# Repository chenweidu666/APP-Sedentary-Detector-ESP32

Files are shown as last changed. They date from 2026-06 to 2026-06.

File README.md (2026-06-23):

# Sedentary Detector ESP32 - 久坐检测器

<p align="center">
  
  
  
  
  
</p>

基于 **ESP32-WROOM-32** + **GY-87**（10DOF，固件用 MPU6050）+ OLED 的椅子久坐检测器。安装在椅子坐垫下方，通过检测坐垫倾斜角度变化判断是否有人坐，超时提醒起身活动。PM11 锂电包供电，USB 充电，**PM11 自带开关**控制电源。

**开发策略**: 全部使用现成开发板模块，设计一块载板 PCB 将各模块插接互连，配合 3D 打印底座固定。模块可拆卸替换，方便快速迭代。

## 当前进度

| 模块 | 状态 |
|---|---|
| 硬件方案 | ✅ 已完成 (ESP32-WROOM-32 + **GY-87** + PM11) |
| 载板 PCB 设计 | 🔧 v0.4 待改版 v0.5（J2 改 GY-87 引脚顺序） |
| Wokwi 仿真 | ✅ 已完成 (ESP32 + MPU6050, 检测算法验证) |
| 固件开发 | 🔧 联调中 (GY-87 / MPU6050 已验证，竖放 ≈90°) |
| 3D 底座 | ⏳ 待设计 |
| 采购 | ⏳ 待下单 |

## 检测原理

MPU6050 加速度计测量重力向量方向。坐下时椅子坐垫受力产生微小倾斜，加速度分量变化，据此判断有人/无人状态。

```
无人状态                         有人状态
┌──────────────┐               ┌──────────────┐
│   ═══坐垫═══  │               │ 👤 ══坐垫══↘  │
│    (水平)     │               │   (倾斜 1-3°) │
│              │               │              │
│  [MPU6050]   │               │  [MPU6050]   │
│  Z轴 = 1g   │               │  Z轴 < 1g    │
│  X/Y轴 ≈ 0  │               │  X/Y轴 ≠ 0   │
└──────────────┘               └──────────────┘
  角度 ≈ 0°                      角度 ≈ 1-3° → 有人！
```

辅助判据：
- **振动检测**: 人坐着会产生持续微振动（翻身、打字、呼吸），无人时完全静止
- **坐下/站起冲击**: 坐下和站起瞬间加速度有明显脉冲

## 系统架构

```
                ┌──────────────────────────────────┐
                │        3D 打印底座 (椅子下方)       │
                │  ┌─ 载板 PCB ─────────────────┐  │
                │  │                            │  │
                │  │  [GY-87]    I2C   [ESP32]  │  │
                │  │  MPU6050 ══════  WROOM-32 │──→ BLE / WiFi
                │  │  (插接)    SDA    (插接)    │  │
                │  │           SCL     ↑ 5V     │  │
                │  │                   │        │  │
                │  │  [PM11]───────────┘        │  │
                │  │  电池包                     │  │
                │  │  (JST)                      │  │
                │  └────────────────────────────┘  │
                │      ↑ PM11 USB 充电口外露        │
                └──────┼───────────────────────────┘
                       │
                    USB 充电
```

## 硬件成本

| 物料 | 型号 | 单价 | 说明 |
|---|---|---|---|
| 主控模块 | ESP32-WROOM-32 开发板 (DevKitC) | ¥35.67 | CP2102 USB 串口, WiFi+BT |
| IMU 模块 | **GY-87**（10DOF，固件用 MPU6050） | ~¥30 | 含 BMP180(`0x77`)，I2C 见 HARDWARE.md |
| 电池模块 | PM11锂电池包 (3.7V+充电+升压5V/2.4A) | ¥19.00 | 内置电池+充电+升压+开关 |
| OLED | SSD1306 128×64 I2C | ~¥8 | 与 GY-87 共 I2C 总线 |
| 载板 PCB | 定制 PCB (嘉立创打样) | ~5.00 | 5片起打, 排母座插接各模块 |
| 排母座 | 2.54mm 排母 | ~2.00 | 焊在载板上, 模块插入 |
| 电池接口 | JST-PH 2.0 座子 | ~0.50 | PM11 电池可插拔 |
| 底座 | 3D 打印 (PLA) | ~3.00 | 固定载板 PCB + 电池 |
| **合计** | | **~¥90** | |

## 文档索引

| 文档 | 内容 |
|---|---|
| [hardware/HARDWARE.md](hardware/HARDWARE.md) | 硬件选型、BOM、接线图、供电设计、PCB载板设计、3D底座 |
| [firmware/FIRMWARE.md](firmware/FIRMWARE.md) | 固件架构、检测算法、状态机、BLE/WiFi通信、功耗管理 |
| [firmware/README.md](firmware/README.md) | 固件编译、烧录、串口联调 |

## 项目结构

```
02-APP-Sedentary-Detector-ESP32/
├── README.md                    # 项目总览 (本文件)
├── hardware/
│   ├── HARDWARE.md              # 硬件设计文档 (选型、BOM、接线、供电、PCB、3D底座)
│   ├── images/                  # 引脚图、模块照片
│   └── kicad/                   # KiCad 载板工程
├── simulation/                  # Wokwi 仿真
│   ├── diagram.json             # 电路连接
│   ├── wokwi.toml               # Wokwi 配置
│   └── src/
│       └── main.cpp             # 仿真固件
├── firmware/                    # ESP32-WROOM-32 固件 (PlatformIO)
│   ├── README.md                # 联调指南
│   ├── FIRMWARE.md              # 架构与算法设计
│   ├── src/
│   │   ├── main.cpp             # 主逻辑 + 串口 bring-up
│   │   ├── detector.h / .cpp    # 久坐检测状态机
│   │   └── config.h             # 引脚与阈值
│   └── platformio.ini           # board=esp32dev
├── mechanical/                  # 3D 打印底座
│   └── base.stl                 # 底座模型 (待设计)
└── docs/
    └── calibration.md           # 校准指南 (待编写)
```

## 开发计划

### Phase 1: 仿真验证 (当前)

- [x] Wokwi 仿真 (ESP32 + MPU6050 + LED)
- [x] 角度检测算法验证
- [x] 久坐计时逻辑
- [ ] 在 Wokwi 中调整参数，确认检测准确率
- [x] 购买 ESP32-WROOM-32 开发板（已联调 USB 烧录）
- [x] GY-87 + ESP32 杜邦线联调（I2C `0x68`/`0x77`）
- [ ] 载板 PCB v0.5：J2 按 GY-87 改走线并打样
- [ ] 面包板搭建原型，验证接线
- [ ] 实测椅子坐下/站起时的角度变化数据
- [ ] 确定安装位置和固定方式

### Phase 2: 载板 PCB + 固件开发

- [ ] 载板 PCB v0.5（J2 GY-87 走线）打样、焊接
- [ ] 固件移植 (Wokwi → 真实硬件)
- [ ] MPU6050 DMP 姿态解算
- [ ] Deep Sleep + RTC 定时唤醒
- [ ] MPU6050 Motion Interrupt 唤醒
- [ ] BLE 广播实现
- [ ] 电池电量检测 (ADC)
- [ ] 功耗实测与优化

### Phase 3: 整合测试

- [ ] 3D 底座设计与打印
- [ ] 载板 + 电池装入底座
- [ ] 安装到椅子上
- [ ] 长时间稳定性测试 (24h+)
- [ ] 误判率统计与阈值调优
- [ ] 实际功耗测量

---

## License

MIT

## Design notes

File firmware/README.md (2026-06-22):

# 固件联调指南

**平台**：ESP32-WROOM-32 + IO 扩展板  
**传感器**：**GY-87**（固件仅使用板载 MPU6050 @ `0x68`）

## 接线（已验证）

| GY-87 丝印 | 扩展板 | GPIO |
| --- | --- | ---- |
| VCC_IN | **3V3** | — |
| GND | **GND** | — |
| SCL | **D5** | GPIO5 |
| SDA | **D4** | GPIO4 |
| INTA | **D2** | GPIO2（可选） |
| 3.3V / FSYNC / DRDY | 不接 | — |

载板 J2 引脚顺序见 [hardware/HARDWARE.md](../hardware/HARDWARE.md)。

## 安装姿态

**竖直立放**（台架）：基准角约 **±90°**（实测 ~97°），看 **delta** 判人。  
**水平安装**（坐垫下）：基准约 0°，装好后串口 `c` 重校准。

## 编译烧录

```bash
cd Projects/02-APP-Sedentary-Detector-ESP32/firmware
pio run -t upload
pio device monitor
```

`MOCK_MPU6050=0`（已接 GY-87）；无传感器时改为 `1`。

## 串口示例

```
[I2C] scan SDA=GPIO4 SCL=GPIO5
  device 0x68
  device 0x77
[MPU6050] connected
[CAL] baseline=97.17 deg (mock=0)
```

`0x77` = GY-87 上 BMP180，可忽略。

## 命令

| 键 | 作用 |
|----|---|
| `r` | I2C 重扫 |
| `c` | 重校准 |
| `m` | 切换 mock（无 MPU 时） |

详细架构见 [FIRMWARE.md](FIRMWARE.md)。

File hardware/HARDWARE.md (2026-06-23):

# 硬件设计文档

> **主控**：ESP32-WROOM-32 开发板（ESP32-DevKitC 风格，2×15 排针载板）。非 ESP32-C3。

## 采购链接

| 模块 | 链接 |
| --- | --- |
| ESP32-WROOM-32 开发板 | https://detail.tmall.com/item.htm?id=805161973303&skuId=5879086331469 |
| 陀螺仪模块 | **GY-87**（10DOF，固件用 MPU6050） | 淘宝/立创搜 GY-87 |
| PM11锂电池包 (3.7V+充电+升压5V/2.4A) | https://item.taobao.com/item.htm?id=1007451636387&skuId=6002389453662 |
| 0.96寸 OLED (I2C) | 128×64 SSD1306, 4Pin (VCC/GND/SCL/SDA) | 淘宝搜 0.96 OLED I2C |

---

## 模块引脚

### ESP32-WROOM-32 开发板 (ESP32-DevKitC 风格)

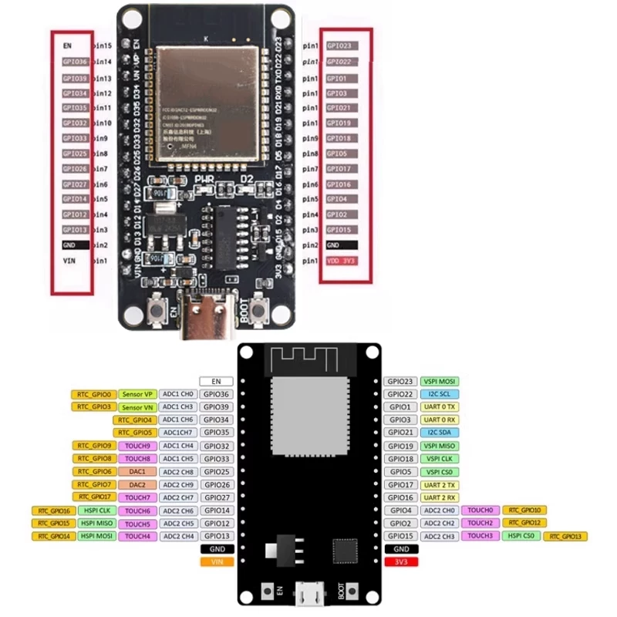
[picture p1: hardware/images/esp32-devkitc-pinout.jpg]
ESP32-WROOM-32 引脚图


```
尺寸: 51.85 × 23.5 mm
引脚: 左列 15pin + 右列 14pin, 2.54mm 间距, 排针间距 23.5mm
安装孔: 4× φ3mm, 距边 3mm
```

#### 左侧引脚 (从上到下, 15 pin)

| Pin | 丝印 | 功能说明 |
| --- | --- | --- |
| 1 | EN | 使能/复位引脚 (高电平有效) |
| 2 | UP (VP) | GPIO36, ADC1_CH0, 仅输入 |
| 3 | UN (VN) | GPIO39, ADC1_CH3, 仅输入 |
| 4 | D34 | GPIO34, ADC1_CH6, 仅输入 |
| 5 | D35 | GPIO35, ADC1_CH7, 仅输入 |
| 6 | D32 | GPIO32, ADC1_CH4 / TOUCH9  |
| 7 | D33 | GPIO33, ADC1_CH5 / TOUCH8  |
| 8 | D25 | GPIO25, ADC2_CH8 / DAC_1 |
| 9 | D26 | GPIO26, ADC2_CH9 / DAC_2 |
| 10  | D27 | GPIO27, ADC2_CH7 / TOUCH7  |
| 11  | D14 | GPIO14, ADC2_CH6 / TOUCH6  |
| 12  | D12 | GPIO12, ADC2_CH5 / TOUCH5  |
| 13  | D13 | GPIO13, ADC2_CH4 / TOUCH4  |
| 14  | GND | 接地 |
| 15  | VIN | 外部电源输入 (5V) |

#### 右侧引脚 (从上到下, 15 pin)

| Pin | 丝印 | 功能说明 |
| --- | ---- | --- |
| 16  | D23  | GPIO23, VSPI MOSI |
| 17  | D22  | GPIO22, I2C SCL (备用) |
| 18  | TXD  | GPIO1, UART0 TXD |
| 19  | RXD  | GPIO3, UART0 RXD |
| 20  | D21  | GPIO21, I2C SDA (备用) |
| 21  | D19  | GPIO19, VSPI MISO |
| 22  | D18  | GPIO18, VSPI SCK |
| 23  | D5 | GPIO5, VSPI SS / I2C SCL |
| 24  | D17  | GPIO17, UART2 TXD |
| 25  | D16  | GPIO16, UART2 RXD |
| 26  | D4 | GPIO4, I2C SDA |
| 27  | D2 | GPIO2, 板载 LED / MPU INT |
| 28  | D15  | GPIO15, U0 RTS |
| 29  | GND  | 接地 |
| 30  | 3V3  | 3.3V 电源输出 |

> ⚠️ 注意事项:
>
> - GPIO34~39 仅输入，无输出、无内上下拉
> - GPIO6~11 被 SPI Flash 占用，不建议使用
> - GPIO12 (D12) 上电影响 Flash 电压 (MTDI)，上电时保持低
> - GPIO0 下载模式 (板子底部 BOOT 按钮)
> - 板载 LED 在 D2 (GPIO2)

### GY-87 模块（正式选型）

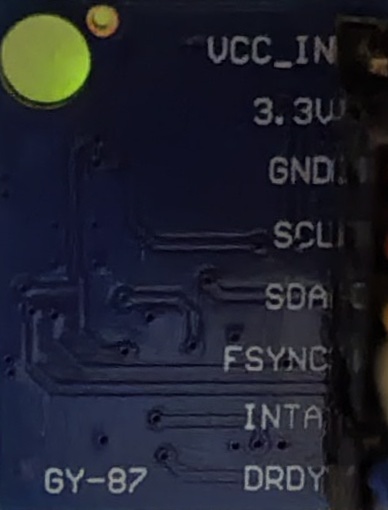
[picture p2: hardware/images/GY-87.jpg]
GY-87 10DOF 模块实物（联调）


10DOF 蓝板，丝印 **GY-87**（MPU6050 + HMC5883L + BMP180）。久坐检测**仅使用 MPU6050 加速度计**，磁力计/气压计与固件无关。

```
引脚: 1 × 8pin 单排, 2.54mm
模块**背面**丝印（如上图，从左至右）: VCC_IN · 3.3V · GND · SCL · SDA · FSYNC · INTA · DRDY
载板 J2 排母（J2 Pin1 = VCC_IN, Pin8 = DRDY），与模块背照丝印顺序一致
```

#### J2 排母引脚映射（载板 / 直插）

| J2 Pin | GY-87 丝印 | 网络 | 连接 |
| --- | --- | ---- | ---- |
| 1 | **VCC_IN** | 3V3 | ESP32 Pin30 (3V3) |
| 2 | **3.3V** | — | **不接**（NC） |
| 3 | **GND** | GND | ESP32 GND |
| 4 | **SCL** | I2C_SCL | ESP32 Pin23 (D5) |
| 5 | **SDA** | I2C_SDA | ESP32 Pin26 (D4) |
| 6 | **FSYNC** | — | NC |
| 7 | **INTA** | MPU_INT | ESP32 Pin27 (D2) |
| 8 | **DRDY** | — | NC |

I2C 扫描：

```
0x68  MPU6050（固件使用）
0x77  BMP180（GY-87 自带，忽略）
0x1E  HMC5883L（可选，固件未用）
```

> **PCB 版本**：原理图 **v0.6** 仅保留 MCU / IMU / OLED / 电源；**PCB v0.4** 走线仍待改后打样。

#### 杜邦线联调（ESP32 扩展板）

| GY-87 丝印 | 扩展板 | 线色（参考） |
| --- | --- | --- |
| VCC_IN | **3V3** | 红 |
| GND | **GND** | 橙 |
| SCL | **D5** | 黄 |
| SDA | **D4** | 绿 |
| INTA | **D2** | 蓝（可选） |
| 3.3V / FSYNC / DRDY | 不接 | — |

联调已验证（2026-06-22）：`0x68` + `0x77`，竖放基准角约 97°，`mock=0` 正常。

---

### 传感器安装姿态

**当前台架**：GY-87 **竖直立放**（芯片面垂直于桌面），非最终椅子安装姿态。

| 姿态 | 典型读数 | 说明 |
| ---- | --- | ---- |
| 水平放置（Z 轴朝上） | 基准角 ≈ **0°** | 最终坐垫下安装目标姿态 |
| **竖直立放（当前）** | 基准角 ≈ **±90°**（实测约 **97°**） | 正常；算法看 **delta**，不是绝对角 |

竖放时上电校准后 `baseline` 约在 **90° 附近**，静止时 `delta` 应 **< 0.5°**、`state=VAC`。  
有人/受压时 **倾斜 1° 以上**（`delta > 1.0°`）才判为 `OCCUPIED`。

**最终产品**：模块应 **水平** 固定在坐垫下方，装好后串口发 `c` 重校准（基准角约 0°）。

### OLED 显示屏

1.54 寸 OLED（SSD1306, 128×64），I2C 接口，与 GY-87 共享 I2C 总线。

| OLED Pin | 网络 | 接 ESP32 |
|---|---|---|
| VCC | 3V3 | Pin30 (3V3) |
| GND | GND | Pin14/29 (GND) |
| SCL | I2C_SCL | Pin23 (D5) |
| SDA | I2C_SDA | Pin26 (D4) |

I2C 地址：**0x3C**（与 GY-87 的 0x68 不冲突）。

### 供电模块 (PM11 电源板)

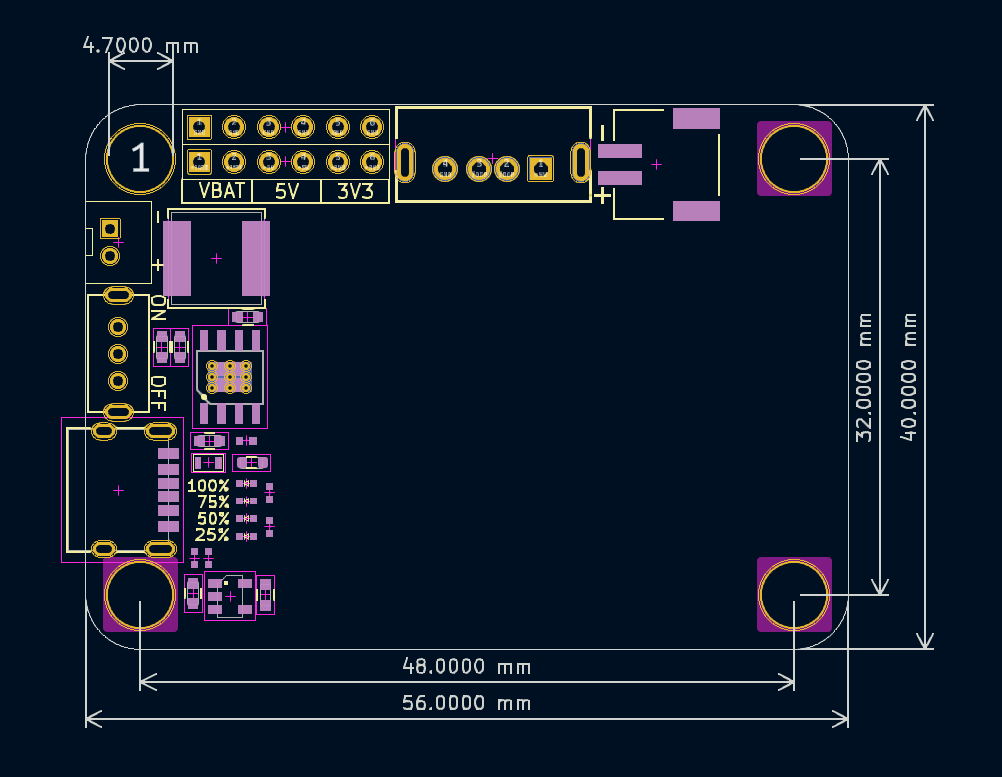
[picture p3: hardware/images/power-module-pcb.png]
供电模块 PCB 布局


集成 **USB 充电 + 锂电管理 + 多路电源输出** 的独立电源板，通过排针向 ESP32 载板供电。

#### 外形尺寸

| 参数 | 值 |
|---|-----|
| PCB 尺寸 | **56.0 × 40.0 mm** |
| 安装孔间距 | 水平 **48.0 mm** × 垂直 **32.0 mm** |
| 安装孔 | 四角 M3（图中标注孔径约 φ4.7 mm，以实物为准） |
| 板厚 | 1.6 mm（常规） |

#### 板载功能

| 功能 | 说明 |
|---|---|
| USB 输入 | 左侧 USB 口，用于充电与外部供电 |
| ON/OFF 开关 | 左侧滑动开关，物理通断输出 |
| 电量指示 | 左侧四档 LED：**100% / 75% / 50% / 25%** |
| 充电管理 | TP4056 类充电 IC + 外围 RC |
| 电池接口 | 顶部 **4Pin** 电池座，丝印 **+ / −** 极性 |
| 电源输出 | 顶部 **2×6** 排针（2.54 mm） |

#### 2×6 排针（本设计关注）

排针位于板子顶部左侧区域；**底排**为常用电源轨（丝印可见）：

| 排针信号 | 说明 | 载板连接 |
|---|---|---|
| **VBAT** | 电池电压（未稳压） | 一般不接 ESP32 |
| **5V** | 升压/稳压 5V 输出 | → ESP32 **Pin15 (VIN)** |
| **3V3** | 3.3V 输出 | 备用；GY-87 从 ESP32 Pin30 取 3V3 |
| GND | 共地 | → ESP32 **Pin14/29** + 载板 GND 铺铜 |

> 上排 6Pin 功能以实物丝印为准；收到模块后**用万用表核对**再焊线。

#### 本设计电源路径

```
USB ──→ [供电模块] ── ON/OFF ──→ 5V 排针 ──→ 载板 ──→ ESP32 Pin15 (VIN)
              │                              │
              └── 电池 (4Pin +/-)             └── GND ──→ ESP32 GND
              └── 电量 LED (100/75/50/25%)

ESP32 板载 LDO: VIN(5V) → 3V3 Pin30 → GY-87 VCC_IN
```

#### 注意事项

1. 电池 **+/−** 切勿接反
2. 开关 OFF 时 ESP32 完全断电；ON 后 5V 才输出到排针
3. 充电时 USB 插入即可，与 ESP32 是否上电无关
4. D2 (GPIO2) 接 GY-87 **INTA**，与 ESP32 板载 LED 共用

---

## 载板全网络表

| 网络 | J1 (ESP32) | J2 (GY-87) | J3 (电源) | J4 (OLED) |
|---|---|---|---|---|
| 3V3 | Pin30 | Pin1(VCC_IN) | — | Pin1(VCC) |
| 5V | Pin15(VIN) | — | Pin2 | — |
| GND | Pin14,29 | Pin3 | Pin1 | Pin2 |
| I2C_SCL | Pin23(D5) | Pin4(SCL) | — | Pin3 |
| I2C_SDA | Pin26(D4) | Pin5(SDA) | — | Pin4 |
| MPU_INT | Pin27(D2) | Pin7(INTA) | — | — |

载板**无**载板级滑动开关与按键；电源通断由 **PM11 自带 ON/OFF** 控制。

---

## 电源路径

```
供电模块 5V 排针 → 载板走线 → ESP32 Pin15 (VIN)
供电模块 GND     → 载板 GND  → ESP32 Pin14/29
```

## 载板 BOM

| # | 元件 | 规格 | 封装 | 数量 |
| - | ---- | ---- | ---- | :--: |
| 1 | ESP32 排母 (左) | 1×15P 2.54mm | 直插 | 1 |
| 2 | ESP32 排母 (右) | 1×15P 2.54mm | 直插 | 1 |
| 3 | GY-87 排母 J2 | 1×8P 2.54mm | 直插 | 1 |
| 4 | OLED 排母 J4 | 1×4P 2.54mm | 直插 | 1 |
| 5 | JST 电源座 J3 | JST-PH 2.0mm 2P | 直插 | 1 |
| 6 | PCB | 100×80mm 2层 1.6mm | - | 5 |

## 固件交互（无载板按键）

校准、切页等通过 **串口命令** 或自动逻辑完成（见 `firmware/FIRMWARE.md`）。

**状态机：** `上电→CALIBRATING(3s)→MONITORING→VACANT/OCCUPIED→ALERT`

**告警解除：** 起身 (Δ<1° 持续3s) 自动解除 → VACANT。

**I2C 设备：**
| 设备 | 地址 |
|---|---|
| MPU6050 (GY-87) | 0x68 |
| BMP180 (GY-87, 忽略) | 0x77 |
| SSD1306 OLED | 0x3C |

## PCB 规格

| 参数 | 值 |
| --- | --- |
| 尺寸 | 100mm × 80mm, 2层 |
| 板厚 | 1.6mm |
| 铜厚 | 1oz |
| 安装孔 | 4× M3 (φ3.2mm), 距边 3mm |
| 线宽 (信号) | 0.254mm |
| 线宽 (电源) | 0.5mm |
| GND | B.Cu 铺铜 |

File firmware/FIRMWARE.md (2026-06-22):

# 固件设计文档

> **平台**：ESP32-WROOM-32（`platformio.ini` 中 `board = esp32dev`）。载板 I2C 为 GPIO4/5，板载 LED 为 GPIO2。
>
> **安装姿态**：台架竖直立放时基准角约 ±90°（实测 ~97°）；水平安装时约 0°。检测使用 `delta = |angle - baseline|`，与绝对角度无关。见 `hardware/HARDWARE.md`。

## 固件架构

```
┌─────────────────────────────────────────────────┐
│                   main.cpp                       │
│              初始化 + 主循环 + Deep Sleep         │
├──────────┬──────────┬───────────┬───────────────┤
│ mpu6050  │ detector │ ble_adv   │    power      │
│ .h/.cpp  │ .h/.cpp  │ .h/.cpp   │   .h/.cpp     │
├──────────┼──────────┼───────────┼───────────────┤
│ MPU6050  │ 久坐检测  │ BLE 广播  │ Deep Sleep    │
│ I2C 驱动  │ 状态机    │ 管理      │ 电源管理      │
│ DMP 姿态  │ 角度判定  │ 状态上报  │ 电池电量      │
│ 加速度读取 │ 滞回去抖  │ 心跳包    │ ADC 检测      │
└──────────┴──────────┴───────────┴───────────────┘
                    │
              config.h
           参数配置 (阈值/时间)
```

## 检测算法

### 状态机

```
            坐下 (角度变化 > 阈值, 持续 3s 确认)
  ┌────────┐ ─────────────────────→ ┌─────────┐
  │  无人   │                        │  有人    │
  │(VACANT)│ ←───────────────────── │(OCCUPIED)│
  └────────┘  站起 (角度恢复, 持续 5s) └────┬────┘
                                        │
                                  连续坐 ≥ 45min
                                        ↓
                                  久坐提醒 (BLE 通知)
                                        │
                                  每隔 15min 再次提醒
```

### 判定算法

```
1. 基准校准 (上电时):
   - 记录无人状态下的基准倾斜角 baseline_angle

2. 每次唤醒:
   - 读取 MPU6050 加速度数据
   - 计算当前倾斜角 current_angle
   - delta = |current_angle - baseline_angle|
   - 计算振动幅度 vibration (加速度标准差)

3. 判定:
   - delta > 1.0° AND vibration > threshold → 有人
   - delta < 0.5° AND vibration < quiet_threshold → 无人
   - 中间值 → 维持当前状态 (滞回)

4. 去抖:
   - 状态切换需连续 N 次 (3-5次) 确认
```

### 参数配置

| 参数 | 默认值 | 说明 |
|---|---|---|
| 采样间隔 | 2s | Deep Sleep RTC 唤醒周期 |
| 角度阈值 (坐下) | 1.0° | 倾斜角变化超过此值判定有人 |
| 角度阈值 (站起) | 0.5° | 回到此范围内判定无人 (滞回) |
| 去抖次数 | 3 次 | 连续确认次数 |
| 久坐阈值 | 45 min | 连续有人超过此时间触发提醒 |
| 重复提醒间隔 | 15 min | 久坐后每隔此时间再次提醒 |
| 心跳间隔 | 5 min | 定时上报状态 |

---

## 通信方式

### BLE 广播 (默认)

无需配对，通过 BLE Manufacturer Specific Data 广播状态：

```
Manufacturer Specific Data (AD Type 0xFF):

Byte 0-1: Company ID = 0xFFFF (测试用)
Byte 2:   Message Type
            0x01 = 状态变化
            0x02 = 心跳
            0x03 = 久坐提醒
            0x04 = 低电量
Byte 3:   Occupancy State (0x00=无人, 0x01=有人)
Byte 4-5: 久坐时长 (uint16, 分钟)
Byte 6:   电池电量 (0-100%)
Byte 7:   当前倾斜角 (int8, 度×10)
```

### WiFi/MQTT (可选)

通过 WiFi 连接 MQTT Broker，上报到 Home Assistant：

```
Topic: home/chair/desk/status      → "occupied" / "vacant"
Topic: home/chair/desk/duration    → 久坐时长 (分钟)
Topic: home/chair/desk/battery     → 电量 (%)
Topic: home/chair/desk/angle       → 当前倾斜角 (度)
```

> WiFi 模式功耗较高 (~100mA 连接时)，建议仅在状态变化时短暂开启 WiFi 上报后关闭。

---

## 电源管理

### Deep Sleep 策略

```
┌──────────────────────────────────────────────┐
│              Deep Sleep 循环                   │
│                                              │
│  RTC 唤醒 (每 2s)                             │
│     │                                        │
│     ↓                                        │
│  读取 MPU6050 (15ms)                          │
│     │                                        │
│     ↓                                        │
│  检测算法判定                                  │
│     │                                        │
│     ├── 状态变化 → BLE 广播 → Deep Sleep      │
│     ├── 久坐提醒 → BLE 广播 → Deep Sleep      │
│     └── 无变化 → 直接 Deep Sleep              │
│                                              │
│  唤醒源:                                       │
│  1. RTC 定时器 (2s)                           │
│  2. MPU6050 INT (运动中断)                     │
└──────────────────────────────────────────────┘
```

### 唤醒源配置

| 唤醒源 | 配置 | 说明 |
|---|---|---|
| RTC 定时器 | 2000ms | 定期采样 MPU6050 |
| MPU6050 INT | GPIO2, 下降沿 | 运动检测中断，加速响应 |

### 电池电量检测

```
ESP32-WROOM-32 ADC → PM11 电池电压分压

- PM11 输出 5V (升压后), 无法直接测电池电压
- 方案: 在 PM11 电池正负极间加分压电阻
- 选用 ADC1 通道引脚（如 GPIO36/39 等仅输入 ADC 脚），读取分压值换算电量
- 低电量阈值: 3.3V (约 10%)
```

### 功耗优化

| 措施 | 效果 |
|---|---|
| Deep Sleep 2s 周期 | 平均功耗 ~0.15mA |
| MPU6050 读取后进入 standby | 减少传感器功耗 |
| BLE 仅在状态变化时广播 | 减少射频功耗 |
| WiFi 按需开启 | 避免持续连接功耗 |
| 关闭未使用外设 | 减少静态漏电 |

---

## 固件模块设计

### mpu6050.h / .cpp - MPU6050 驱动

```cpp
class MPU6050Driver {
public:
    void init();                    // I2C 初始化
    void calibrate();               // 上电校准基准角度
    float readAngle();              // 读取当前倾斜角
    float readVibration();          // 读取振动幅度 (加速度标准差)
    void setMotionInterrupt();      // 配置运动检测中断
    void sleep();                   // MPU6050 进入低功耗
    void wake();                    // MPU6050 唤醒
};
```

### detector.h / .cpp - 久坐检测算法

```cpp
class SedentaryDetector {
public:
    enum State { VACANT, OCCUPIED };

    void init();                    // 初始化, 记录基准角度
    State update(float angle, float vibration);  // 状态更新
    State getState();               // 获取当前状态
    uint16_t getDuration();         // 获取连续久坐时长 (分钟)
    void reset();                   // 重置计时器
};
```

### ble_adv.h / .cpp - BLE 广播管理

```cpp
class BLEAdvertiser {
public:
    void init();                    // BLE 初始化
    void broadcastState(State state, uint16_t duration,
                        uint8_t battery, int8_t angle);  // 广播状态
    void broadcastHeartbeat();      // 心跳包
    void broadcastAlert();          // 久坐提醒
    void broadcastLowBattery();     // 低电量告警
};
```

### power.h / .cpp - 电源管理

```cpp
class PowerManager {
public:
    void init();                    // 电源初始化
    void enterDeepSleep(uint64_t us);  // 进入 Deep Sleep
    uint8_t readBatteryLevel();     // 读取电池电量 (%)
    bool isLowBattery();            // 低电量判断
};
```

### config.h - 参数配置

```cpp
// 采样参数
#define SAMPLE_INTERVAL_US      2000000ULL    // 2s (us)
#define ANGLE_THRESHOLD_SEAT    1.0f          // 坐下角度阈值 (°)
#define ANGLE_THRESHOLD_STAND   0.5f          // 站起角度阈值 (°)
#define DEBOUNCE_COUNT          3             // 去抖次数

// 久坐参数
#define SEATED_THRESHOLD_MIN    45            // 久坐阈值 (分钟)
#define REMINDER_INTERVAL_MIN   15            // 重复提醒间隔 (分钟)
#define HEARTBEAT_INTERVAL_MIN  5             // 心跳间隔 (分钟)

// 电池参数
#define LOW_BATTERY_THRESHOLD   10            // 低电量阈值 (%)
#define BATTERY_ADC_PIN         GPIO_NUM_36   // ADC1_CH0（仅输入，需外部分压）
```

---

## main.cpp 主流程

```cpp
void setup() {
    // 1. 初始化各模块
    power.init();
    mpu6050.init();
    detector.init();
    ble.init();

    // 2. 校准基准角度 (上电时)
    mpu6050.calibrate();

    // 3. 配置 Deep Sleep 唤醒源
    esp_sleep_enable_timer_wakeup(SAMPLE_INTERVAL_US);
    esp_sleep_enable_ext0_wakeup(MPU6050_INT_PIN, LOW);
}

void loop() {
    // 1. 读取传感器
    float angle = mpu6050.readAngle();
    float vibration = mpu6050.readVibration();

    // 2. 更新检测状态
    SedentaryDetector::State newState = detector.update(angle, vibration);

    // 3. 状态变化时广播
    if (newState != lastState) {
        ble.broadcastState(newState, detector.getDuration(),
                          power.readBatteryLevel(), (int8_t)(angle * 10));
        lastState = newState;
    }

    // 4. 久坐提醒
    if (newState == SedentaryDetector::OCCUPIED &&
        detector.getDuration() >= SEATED_THRESHOLD_MIN) {
        ble.broadcastAlert();
    }

    // 5. 心跳包
    if (millis() - lastHeartbeat > HEARTBEAT_INTERVAL_MIN * 60000) {
        ble.broadcastHeartbeat();
        lastHeartbeat = millis();
    }

    // 6. 进入 Deep Sleep
    mpu6050.sleep();
    esp_deep_sleep_start();
}
```

---

## PlatformIO 工程配置

当前工程（见 `platformio.ini`）：

```ini
[env:esp32dev]
platform = espressif32
board = esp32dev
framework = arduino
monitor_speed = 115200
build_flags =
    -DCORE_DEBUG_LEVEL=3
    -DMOCK_MPU6050=1    ; 无传感器联调时保持 1；接上 MPU6050 后改为 0
lib_deps =
    electroniccats/MPU6050@^1.4.3
```

烧录与串口联调步骤见 [README.md](README.md)。

## 开发工具链

| 工具 | 用途 |
|---|---|
| PlatformIO (VSCode) | 固件开发 IDE |
| Wokwi | 在线仿真验证 |
| ESP-IDF | 底层 SDK (可选) |
| nRF Connect | BLE 广播测试 |
| MQTT Explorer | WiFi/MQTT 调试 |

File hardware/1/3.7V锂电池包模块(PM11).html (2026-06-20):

# emakefun文档中心 (https://docs.emakefun.com/)

emakefun

- 首页 (https://docs.emakefun.com/#/zh-cn/homepage)
- 软件介绍
  - 软件下载 (https://docs.emakefun.com/#/zh-cn/software/software_download.zh-CN)
  - ArduinoIDE2.0介绍 (https://docs.emakefun.com/#/zh-cn/software/arduino_ide/arduino_ide.zh-CN)
  - Mixly2.0使用介绍 (https://docs.emakefun.com/#/zh-cn/software/mixly/mixly)
  - Mind+使用介绍 (https://docs.emakefun.com/#/zh-cn/software/mind_plus/mindplus.zh-CN)
  - Thonny使用介绍 (https://docs.emakefun.com/#/zh-cn/software/thonny/thonny.zh-CN)
  - MagicBlock使用介绍 (https://docs.emakefun.com/#/zh-cn/software/MagicBlock_pic_zh/magicblock)
  - 手机编程软件介绍 (https://docs.emakefun.com/#/zh-cn/software/Mobile_programming/Mobile_programming)
- 驱动安装
  - arduino官方驱动安装 (https://docs.emakefun.com/#/zh-cn/driver/arduino_official_driver/arduino_official_driver)
  - ch340驱动安装方法 (https://docs.emakefun.com/#/zh-cn/driver/ch340_driver/ch340_driver)
  - microbit daplink驱动安装 (https://docs.emakefun.com/#/zh-cn/driver/microbit_daplink_driver/microbit_daplink_driver)
  - esp32 usb驱动安装 (https://docs.emakefun.com/#/zh-cn/driver/esp32_driver/esp32_driver)
- PH2.0模块
  - 基础输入模块
    - 按键模块 (https://docs.emakefun.com/#/zh-cn/ph2.0_sensors/base_input_module/button_module/button_module)
    - ADC按键模块 (https://docs.emakefun.com/)
    - 触摸模块 (https://docs.emakefun.com/#/zh-cn/ph2.0_sensors/base_input_module/touch_module/touch_module_zh-cn)
    - 碰撞开关 (https://docs.emakefun.com/)
    - 旋转电位器 (https://docs.emakefun.com/)
    - 滑动变阻器 (https://docs.emakefun.com/)
    - 旋转编码器 (https://docs.emakefun.com/)
    - 摇杆模块 (https://docs.emakefun.com/#/zh-cn/ph2.0_sensors/base_input_module/rocker_module/rocker_module_zh-cn)
    - 触摸矩阵键盘V3.0 (https://docs.emakefun.com/)
    - 触摸钢琴V2.0 (https://docs.emakefun.com/#/zh-cn/ph2.0_sensors/base_input_module/touch_piano/touch_piano)
    - mini-joystick手柄 (https://docs.emakefun.com/#/zh-cn/ph2.0_sensors/base_input_module/mini-joystick/mini-joystick_zh-cn)
    - 自发电无线开关 (https://docs.emakefun.com/#/zh-cn/gallery)
  - 传感器
    - 声音传感器 (https://docs.emakefun.com/#/zh-cn/ph2.0_sensors/sensors/sound_sensor/sound_sensor)
    - DHT11温湿度 (https://docs.emakefun.com/#/zh-cn/ph2.0_sensors/sensors/dht11/dht11_zh-cn)
    - DHT22温湿度 (https://docs.emakefun.com/#/zh-cn/ph2.0_sensors/sensors/dht22/dht22_zh-cn)
    - AHT20温湿度 (https://docs.emakefun.com/#/zh-cn/ph2.0_sensors/sensors/aht20/aht20_zh-cn)
    - 光敏传感器 (https://docs.emakefun.com/)
    - NTC热敏传感器 (https://docs.emakefun.com/#/zh-cn/ph2.0_sensors/sensors/thermal_sensor/thermal_sensor)
    - LM35温度传感器 (https://docs.emakefun.com/#/zh-cn/ph2.0_sensors/sensors/lm35/lm35)
    - NL50温度传感器 (https://docs.emakefun.com/#/zh-cn/ph2.0_sensors/sensors/temperature_sensor_nl50/nl50_zh-cn)
    - DS18B20温度传感器 (https://docs.emakefun.com/#/zh-cn/ph2.0_sensors/sensors/ds18b20_sensor/ds18b20_sensor)
    - 火焰传感器 (https://docs.emakefun.com/#/zh-cn/ph2.0_sensors/sensors/flame_sensor/flame_sensor_zh-cn)
    - 土壤湿度传感器 (https://docs.emakefun.com/#/zh-cn/ph2.0_sensors/sensors/soil_moisture_sensor/soil_moisture_sensor)
    - 雨滴传感器 (https://docs.emakefun.com/#/zh-cn/ph2.0_sensors/sensors/water_droplets_sensor/water_droplets_sensor)
    - 水深传感器 (https://docs.emakefun.com/#/zh-cn/ph2.0_sensors/sensors/water_depth_sensor/water_depth_sensor)
    - 气体传感器 (https://docs.emakefun.com/#/zh-cn/ph2.0_sensors/sensors/mq_gas_sensor/mq_gas_sensor)
    - 人体热释电传感器 (https://docs.emakefun.com/#/zh-cn/ph2.0_sensors/sensors/human_body_sensor/human_body_sensor)
    - 磁簧开关 (https://docs.emakefun.com/)
    - 霍尔开关 (https://docs.emakefun.com/#/zh-cn/ph2.0_sensors/sensors/hall_switch/hall_switch)
    - 灰度传感器 (https://docs.emakefun.com/#/zh-cn/ph2.0_sensors/sensors/grayscale_sensor/grayscale_sensor)
    - 震动传感器 (https://docs.emakefun.com/#/zh-cn/ph2.0_sensors/sensors/shock_sensor/shock_sensor)
    - 四向倾斜开关 (https://docs.emakefun.com/#/zh-cn/ph2.0_sensors/sensors/tilt_switch_sensor/tilt_switch_sensor_zh-cn)
    - 压力传感器 (https://docs.emakefun.com/#/zh-cn/ph2.0_sensors/sensors/pressure_sensor/pressure_sensor)
    - RGB超声波传感器 (https://docs.emakefun.com/#/zh-cn/ph2.0_sensors/sensors/rus_04/rus_04)
    - 普通超声波传感器 (https://docs.emakefun.com/#/zh-cn/ph2.0_sensors/sensors/us04_us03/us04_us03)
    - 红外接收模块 (https://docs.emakefun.com/#/zh-cn/ph2.0_sensors/sensors/infrared_receiver/infrared_receiver_zh-cn.md)
    - 红外避障 (https://docs.emakefun.com/)
    - 红外寻光避障 (https://docs.emakefun.com/#/zh-cn/gallery)
    - 红外计数传感器 (https://docs.emakefun.com/#/zh-cn/ph2.0_sensors/sensors/Infrared_counter/Infrared_counter)
    - 红外循迹模块 (https://docs.emakefun.com/#/zh-cn/ph2.0_sensors/sensors/tracking_sensor/tracking_sensor)
    - 五路红外循迹V3.0 (https://docs.emakefun.com/#/zh-cn/ph2.0_sensors/sensors/five_line_tracker_v3/five_line_tracker_v3)
    - 单路灰度循迹模块 (https://docs.emakefun.com/)
    - 五路灰度循迹模块 (https://docs.emakefun.com/)
    - HX711称重模块 (https://docs.emakefun.com/#/zh-cn/)
    - LTR553 (https://docs.emakefun.com/#/zh-cn/)
    - VL53L1X FOV激光测距 (https://docs.emakefun.com/#/zh-cn/ph2.0_sensors/sensors/laser_ranging_sensor/laser_ranging_sensor)
    - PM2.5粉尘传感器 (https://docs.emakefun.com/#/zh-cn/ph2.0_sensors/sensors/pm2.5_dust_sensor/pm2.5_dust_sensor)
  - 执行器
    - 有源蜂鸣器模块 (https://docs.emakefun.com/#/zh-cn/ph2.0_sensors/actuators/active_buzzer/active_buzzer_zh-cn)
    - 无源蜂鸣器模块 (https://docs.emakefun.com/#/zh-cn/ph2.0_sensors/actuators/passive_buzzer/passive_buzzer_zh-cn)
    - SA8302步进电机模块 (https://docs.emakefun.com/#/zh-cn/ph2.0_sensors/actuators/SA8302/SA8302)
    - 空心杯610电机风扇 (https://docs.emakefun.com/)
    - R300C电机风扇 (https://docs.emakefun.com/#/zh-cn/ph2.0_sensors/actuators/R300C/R300C_zh-cn)
    - 继电器模块 (https://docs.emakefun.com/#/zh-cn/ph2.0_sensors/actuators/relay_module/relay_model_zh-cn)
    - 红外发射模块 (https://docs.emakefun.com/#/zh-cn/ph2.0_sensors/actuators/infrared_emitter/infrared_emitter_zh-cn)
    - 激光发射模块 (https://docs.emakefun.com/#/zh-cn/ph2.0_sensors/actuators/laser_emitter/laser_emitter_zh-cn)
    - 振动马达 (https://docs.emakefun.com/#/zh-cn/ph2.0_sensors/actuators/vibrationMotorModule/vibrationMotorModule)
    - 8002A音频放大器 (https://docs.emakefun.com/#/zh-cn/ph2.0_sensors/actuators/8002a_amp_speaker/8002a_amp_speaker)
    - 舵机扩展 (https://docs.emakefun.com/#/zh-cn/ph2.0_sensors/actuators/servo_adapter_zh-cn)
    - MD01单路电机驱动 (https://docs.emakefun.com/#/zh-cn/ph2.0_sensors/actuators/md01/md01_zh-cn)
    - MD02双路电机驱动 (https://docs.emakefun.com/#/zh-cn/ph2.0_sensors/actuators/md02/md02_zh-cn)
    - DM11两路电机驱动模块 (https://docs.emakefun.com/#/zh-cn/ph2.0_sensors/actuators/dm11/dm11)
    - MD40四路编码驱动模块 (https://docs.emakefun.com/#/zh-cn/ph2.0_sensors/actuators/md40/md40)
    - 小型雾化器 (https://docs.emakefun.com/#/zh-cn/ph2.0_sensors/actuators/small_atomizer/small_atomizer_zh-cn)
    - MOS管驱动模块 (https://docs.emakefun.com/#/zh-cn/ph2.0_sensors/actuators/mos_driver_module/mos_driver_module_zh-cn)
  - 显示器
    - LED灯 (https://docs.emakefun.com/#/zh-cn/ph2.0_sensors/displayers/led_module/LED)
    - LCD1602显示屏 (https://docs.emakefun.com/#/zh-cn/ph2.0_sensors/displayers/lcd1602/LCD1602)
    - TM1650四位数码管 (https://docs.emakefun.com/#/zh-cn/ph2.0_sensors/displayers/tm1650/TM1650)
    - TM1637四位时钟数码管 (https://docs.emakefun.com/#/zh-cn/ph2.0_sensors/displayers/tm1637/TM1637)
    - VK16K33四位数码管 (https://docs.emakefun.com/#/zh-cn/ph2.0_sensors/displayers/vk16k33/vk16k33)
    - MAX7289_8x8点阵屏 (https://docs.emakefun.com/#/zh-cn/ph2.0_sensors/displayers/8x8_dot_matrix/8x8LedDisplay)
    - MAX7289_8x32点阵屏 (https://docs.emakefun.com/#/zh-cn/ph2.0_sensors/displayers/8x32_dot_matrix/8x32_dot_matrix)
    - 交通信号灯 (https://docs.emakefun.com/#/zh-cn/ph2.0_sensors/displayers/trafficlight_module/trafficLights)
    - RGB全彩灯 (https://docs.emakefun.com/#/zh-cn/ph2.0_sensors/displayers/rgb_module/RGB)
    - WS2812B RGB灯环 (https://docs.emakefun.com/#/zh-cn/ph2.0_sensors/displayers/ws2812b/ws2812b_zh-cn)
    - 中文字库0.96OLED (https://docs.emakefun.com/#/zh-cn/ph2.0_sensors/displayers/GT20L16S1Y_OLED/GT20L16S1Y_OLED)
    - SWIFT-LCD-13显示屏模块 (https://docs.emakefun.com/#/zh-cn/ph2.0_sensors/displayers/swift_lcd_13/swift_lcd_13)
    - SWIFT-LCD-20显示屏模块 (https://docs.emakefun.com/#/zh-cn/ph2.0_sensors/displayers/swift_lcd_20/swift_lcd_20)
  - 智能模块
    - BMP280大气压传感器 (https://docs.emakefun.com/)
    - TCS34725颜色识别 (https://docs.emakefun.com/#/zh-cn/ph2.0_sensors/smart_module/color_recognition/color_recognition)
    - NLCS11颜色识别 (https://docs.emakefun.com/#/zh-cn/ph2.0_sensors/smart_module/color_sensor_nlcs11/color_sensor_nlcs11)
    - QMC5883L电子指南针罗盘模块 (https://docs.emakefun.com/#/zh-cn/ph2.0_sensors/smart_module/compass/compass)
    - DS1302时钟模块 (https://docs.emakefun.com/#/zh-cn/ph2.0_sensors/smart_module/ds1302/ds1302_rtc)
    - DS1307时钟模块 (https://docs.emakefun.com/#/zh-cn/ph2.0_sensors/smart_module/ds1307/ds1307_rtc)
    - MPU6050六轴陀螺仪 (https://docs.emakefun.com/#/zh-cn/ph2.0_sensors/smart_module/mpu6050/mpu6050)
    - 计步传感器 (https://docs.emakefun.com/#/zh-cn/gallery)
    - GS20手势识别传感器 (https://docs.emakefun.com/#/zh-cn/ph2.0_sensors/smart_module/gesture_recognizer/gesture_recognizer)
    - MP3播放模块 (https://docs.emakefun.com/#/zh-cn/ph2.0_sensors/smart_module/mp3_module/MP3)
    - I2S音频放大器模块 (https://docs.emakefun.com/)
    - ESP8266 MQTT模块 (https://docs.emakefun.com/#/zh-cn/ph2.0_sensors/smart_module/esp8266_mqtt/esp8266_mqtt)
    - ESP32 C2 MQTT模块 (https://docs.emakefun.com/#/zh-cn/ph2.0_sensors/smart_module/esp32_c2_mqtt/esp32_c2_mqtt)
    - LD3320语音识别V2.1 (https://docs.emakefun.com/#/zh-cn/ph2.0_sensors/smart_module/speech_recognizer/speech_recognizer)
    - 离线特定语音识别ASR-V2 (https://docs.emakefun.com/)
    - TTS20 语音合成模块 (https://docs.emakefun.com/#/zh-cn/ph2.0_sensors/smart_module/tts20_module/tts20_module)
    - TTS语音合成V2.1 (https://docs.emakefun.com/#/zh-cn/ph2.0_sensors/smart_module/tts_module/text_to_speech_synthesizer)
    - MIDI数字音乐模块 (https://docs.emakefun.com/#/zh-cn/ph2.0_sensors/smart_module/midi/midi)
    - I2C-IO扩展模块 (https://docs.emakefun.com/)
    - I2C级联扩展器 (https://docs.emakefun.com/)
    - RFID-I2C模块 (https://docs.emakefun.com/#/zh-cn/ph2.0_sensors/smart_module/rfid_mfrc522/rfid_mfrc522)
    - I2S-MEMS麦克风模块 (https://docs.emakefun.com/#/zh-cn/ph2.0_sensors/smart_module/i2s_mems_mic/i2s_mems_mic)
    - PDM麦克风模块 (https://docs.emakefun.com/#/zh-cn/ph2.0_sensors/smart_module/pdm_mic/pdm_mic)
    - 指纹识别模块 (https://docs.emakefun.com/#/zh-cn/)
    - 毫米波雷达模块 (https://docs.emakefun.com/#/zh-cn/)
    - GPS模块 (https://docs.emakefun.com/#/zh-cn/)
    - AI语音助手 (https://docs.emakefun.com/#/zh-cn/ph2.0_sensors/smart_module/ai_voice_assistant/ai_voice_assistant)
- 电源模块
  - 5V5A电源模块(PM01) (https://docs.emakefun.com/#/zh-cn/power_module/PM01/PM01)
  - 升降压5V电源(PM02) (https://docs.emakefun.com/#/zh-cn/power_module/PM02/PM02)
  - MPPT太阳能充电板 (https://docs.emakefun.com/#/zh-cn/power_module/MPPT/MPPT_zh-cn)
  - 3.7V升压充电模块(PM1S-16340) (https://docs.emakefun.com/#/zh-cn/power_module/PM1S-16340/PM1S-16340)
  - 3.7V锂电池包模块(PM11) (https://docs.emakefun.com/#/zh-cn/power_module/PM11/PM11)
    - 概述 (https://docs.emakefun.com/#/zh-cn/power_module/PM11/PM11?id=%e6%a6%82%e8%bf%b0)
    - 模块参数 (https://docs.emakefun.com/#/zh-cn/power_module/PM11/PM11?id=%e6%a8%a1%e5%9d%97%e5%8f%82%e6%95%b0)
      - 功能示意图： (https://docs.emakefun.com/)
    - LED状态说明 (https://docs.emakefun.com/#/zh-cn/power_module/PM11/PM11?id=led%e7%8a%b6%e6%80%81%e8%af%b4%e6%98%8e)
    - 机械尺寸图 (https://docs.emakefun.com/)
  - 7.4V充电电池模块(PM2S-16340) (https://docs.emakefun.com/#/zh-cn/power_module/PM2S-16340/PM2S-16340)
  - 双节18650锂电池充电模块 (https://docs.emakefun.com/#/zh-cn/power_module/18650_2s_li_battery_module/18650_2s_li_battery_module)
  - 三节18650锂电池充电模块 (https://docs.emakefun.com/zh-cn//power_module/18650_3s_li_battery_module.md)
- Arduino产品
  - Nano
    - nano-v3.0 (https://docs.emakefun.com/#/zh-cn/arduino_products/nano/nano/nano)
    - ble-nano (https://docs.emakefun.com/#/zh-cn/arduino_products/nano/ble-nano/README_zh)
    - rf-nano (https://docs.emakefun.com/#/zh-cn/arduino_products/nano/rf-nano/README_zh)
    - nano开发者套件 (https://docs.emakefun.com/#/zh-cn/)
  - Uno系列
    - arduino_uno_r3 (https://docs.emakefun.com/#/zh-cn/arduino_products/uno/arduino_uno_r3/arduino_uno_r3)
    - ble-uno (https://docs.emakefun.com/#/zh-cn/arduino_products/uno/ble-uno/ble_uno)
    - maker-uno (https://docs.emakefun.com/#/zh-cn/arduino_products/uno/maker-uno/maker_uno)
    - PH2.0传感器扩展板 (https://docs.emakefun.com/#/zh-cn/arduino_products/uno/sensorkit/SensorKit)
    - motor_driver_board (https://docs.emakefun.com/#/zh-cn/arduino_products/uno/motor_driver_board/motor_driver_board)
    - hummer-bot (https://docs.emakefun.com/#/zh-cn/arduino_products/uno/hummer-bot/hummer-bot)
    - panther-tank (https://docs.emakefun.com/#/zh-cn/arduino_products/uno/panther_tank/panther_tank)
    - 传感器套件介绍 (https://docs.emakefun.com/#/zh-cn/)
- micro:bit
  - microbit主板介绍 (https://microbit.org/zh-cn/get-started/features/overview/)
  - makecode介绍 (https://docs.emakefun.com/#/zh-cn/microbit/makecode/MakeCode%E4%BD%BF%E7%94%A8%E4%BB%8B%E7%BB%8D)
  - microbit micropython介绍 (https://docs.emakefun.com/#/zh-cn/microbit/microbit_micropython/microbit_micropython)
  - io:bit (https://docs.emakefun.com/#/zh-cn/microbit/IObit/IObit)
  - sensor:bit (https://docs.emakefun.com/#/zh-cn/microbit/sensorbit/sensorbit)
  - motor:bit (https://docs.emakefun.com/#/zh-cn/microbit/motorbit/motorbit)
  - joysitck:bit (https://docs.emakefun.com/#/zh-cn/microbit/joystickbit/joystickbit)
- 乐鑫esp系类
  - esp32软件使用 (https://docs.emakefun.com/#/zh-cn/esp32/esp32_software_instructions/esp32_software_instructions)
  - esp32-devkit-32e (https://docs.emakefun.com/#/zh-cn/esp32/esp32_devkit_32e/esp32_devkit_32e)
  - esp32-uno (https://docs.emakefun.com/#/zh-cn/esp32/esp32-uno/esp32-uno)
  - esp32-iot-board (https://docs.emakefun.com/#/zh-cn/esp32/esp32_iot_board/esp32_iot_board)
  - maker-esp32-mini (https://docs.emakefun.com/#/zh-cn/esp32/maker-esp32-mini/maker-esp32-mini)
  - maker-esp32 (https://docs.emakefun.com/#/zh-cn/esp32/maker_esp32/maker_esp32)
  - maker-esp32-pro (https://docs.emakefun.com/#/zh-cn/esp32/maker_esp32_pro/maker_esp32_pro)
  - esp32-cam V2 (https://docs.emakefun.com/#/zh-cn/esp32/ESP32_CAM/ESP32_CAM)
  - 物联板iot:bit (https://docs.emakefun.com/#/zh-cn/esp32/iotbit/iotbit)
  - nl-esp32-s3-devkitc (https://docs.emakefun.com/#/zh-cn/esp32/nl-esp32-s3-devkitc/README_zh)
  - esp32s3-cam (https://docs.emakefun.com/#/zh-cn/esp32/esp32s3-cam/README_zh)
  - scratch arcade (https://arcade.blockcode.fun/#/zh-cn/intro)
  - AI-VOX3 (https://docs.emakefun.com/#/zh-cn/esp32/ai-vox3/ai-vox3_zh-cn)
  - AI-VOX3扩展板 (https://dcnmu33qx4fc.feishu.cn/docx/Cf49d141voj8JAxNyTJcW5zTned)
  - ESP32-S3-EXPANSION BOARD (https://docs.emakefun.com/#/zh-cn/esp32/esp32-s3-expansion_board/esp32-s3-expansion_board)
- 树莓派
  - 树莓派传感器扩展板 (https://docs.emakefun.com/#/zh-cn/raspberrypi/raspberrypi_sensor_board/raspberrypi_sensor_board)
  - 树莓派电机驱动板 (https://docs.emakefun.com/)
- k210产品
- 开源硬件
  - 机器人驱动板 (https://docs.emakefun.com/#/zh-cn/)
- 外设/配件
  - NL-16 (https://docs.emakefun.com/#/zh-cn/peripheral/nl-16/nl-16_zh-cn)
  - PS2手柄 (https://docs.emakefun.com/#/zh-cn/peripheral/ps2/ps2)
  - PS3蓝牙手柄 (https://docs.emakefun.com/#/zh-cn/peripheral/bluetooth_gamepad_ps3/bluetooth_gamepad_ps3)
  - gamepad (https://docs.emakefun.com/#/zh-cn/peripheral/arduino_gamepad/Programmable_controller)
  - 编码电机 (https://docs.emakefun.com/#/zh-cn/ph2.0_sensors/actuators/hall_encoder_sensor/hall_encoder_sensor)
  - 舵机 (https://docs.emakefun.com/#/zh-cn/peripheral/servo/servo)
  - CodexPad
    - 常见遥控器对比 (https://docs.emakefun.com/#/zh-cn/peripheral/codexpad/wireless_controller_diffrent)
    - CodexPad-C10 (https://docs.emakefun.com/#/zh-cn/peripheral/codexpad/codexpad_c10/codexpad_c10)
    - CodexPad-S10 (https://docs.emakefun.com/#/zh-cn/peripheral/codexpad/codexpad_s10/codexpad_s10)
- 关于我们 (https://docs.emakefun.com/#/zh-cn/about)

# PM11充电升压模块 (https://docs.emakefun.com/)

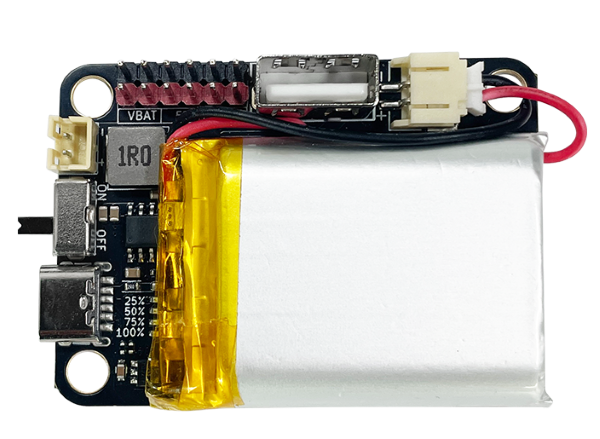
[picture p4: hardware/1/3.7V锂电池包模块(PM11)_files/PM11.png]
PM11


## 概述 (https://docs.emakefun.com/#/zh-cn/power_module/PM11/PM11?id=%e6%a6%82%e8%bf%b0)

该充电模块为3.7V锂电池充电升压5V一体模块，板载1200mA锂电池包。通过TypeC接口即可为板载锂电池提供最高1.2A的安全高效充电。板子上提供了PH2.0-2Pin ，2pin排针锂电池直接输出，USBA口、2pin排针5V/2.4A输出，2Pin排针3.3V 800mA输出。多种电压输出，非常方便应用在多种电压低功耗应用场景需求。且充电芯片自带过充，反接，过载保护。

## 模块参数 (https://docs.emakefun.com/#/zh-cn/power_module/PM11/PM11?id=%e6%a8%a1%e5%9d%97%e5%8f%82%e6%95%b0)

- USB充电 ：TypeC接口 5V最高充电电流1.2A；
- 转换效率：充电升压转换效率90%；
- 电压输出：2pin PH2.0、排针锂电池输出，USBA口 、2pin排针5V/2.4A输，2Pin排针3.3V 800mA输出；
- 电池类型：1200mA锂电池包(充满电压4.2V)；
- 模块尺寸： 56 * 40mm ；
- 安装方式：M4螺钉螺母固定；
- 电池过充/反接/过载保护。

### 功能示意图： (https://docs.emakefun.com/)

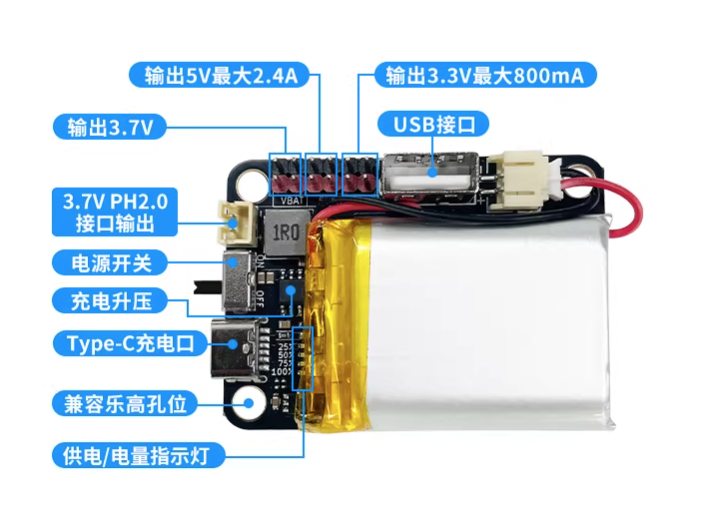
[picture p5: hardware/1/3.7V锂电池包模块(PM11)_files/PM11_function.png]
PM11_function


## LED状态说明 (https://docs.emakefun.com/#/zh-cn/power_module/PM11/PM11?id=led%e7%8a%b6%e6%80%81%e8%af%b4%e6%98%8e)

状态 | 描述
Power指示灯 | 拨动开关ON时，四个LED灯会闪一下，无负载输出的时候，所有灯熄灭
电量 | 4个LED灯分布代表25%，50%，75%，100%电量
充电 | 4灯逐个电流代表在充电中，全亮代表充满

## 机械尺寸图 (https://docs.emakefun.com/)

PM11_assembly

下载PM11平面和3D文件 (https://docs.emakefun.com/zh-cn/power_module/PM11/PM11_3D.zip)

上一篇 (https://docs.emakefun.com/#/zh-cn/power_module/PM1S-16340/PM1S-16340)

3.7V升压充电模块(PM1S-16340)

电源模块

下一篇 (https://docs.emakefun.com/#/zh-cn/power_module/PM2S-16340/PM2S-16340)

7.4V充电电池模块(PM2S-16340)

电源模块

Powered by docsify (https://github.com/docsifyjs/docsify).© 2024emakefun文档中心 (https://github.com/emakefun/emakefun-docsify/).

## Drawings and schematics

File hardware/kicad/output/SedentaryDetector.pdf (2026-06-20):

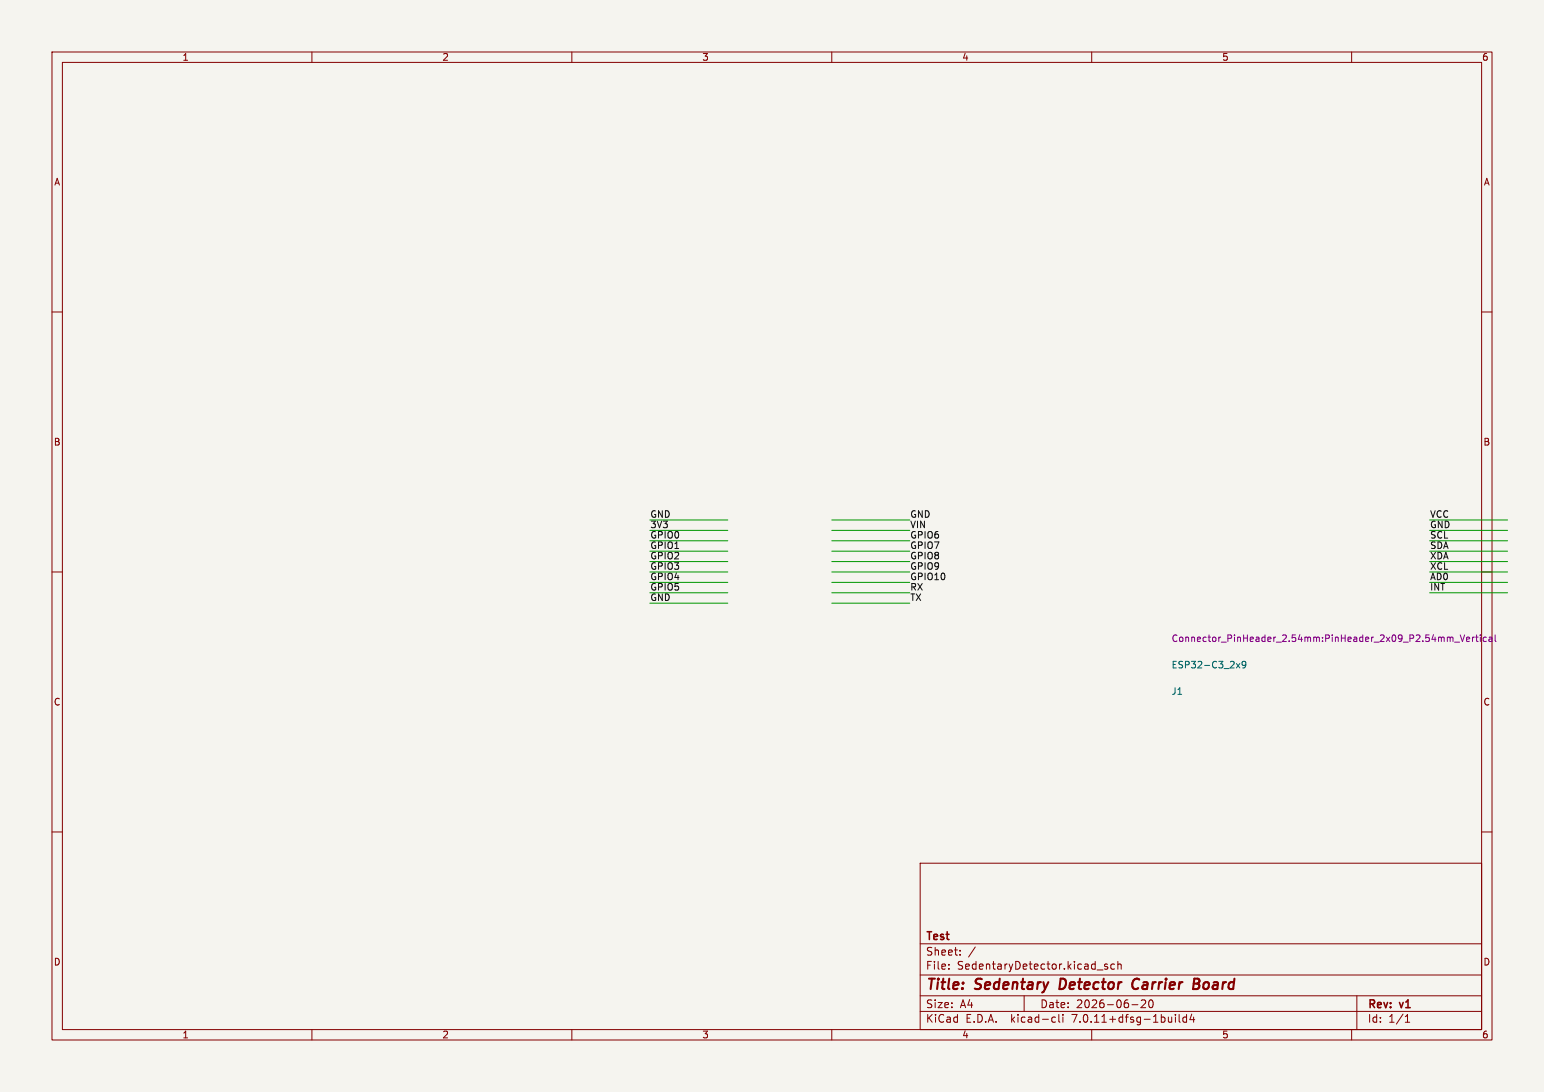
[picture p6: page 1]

File: SedentaryDetector.kicad_sch Sheet: / Test

Id: 1/1 Title: Sedentary Detector Carrier Board

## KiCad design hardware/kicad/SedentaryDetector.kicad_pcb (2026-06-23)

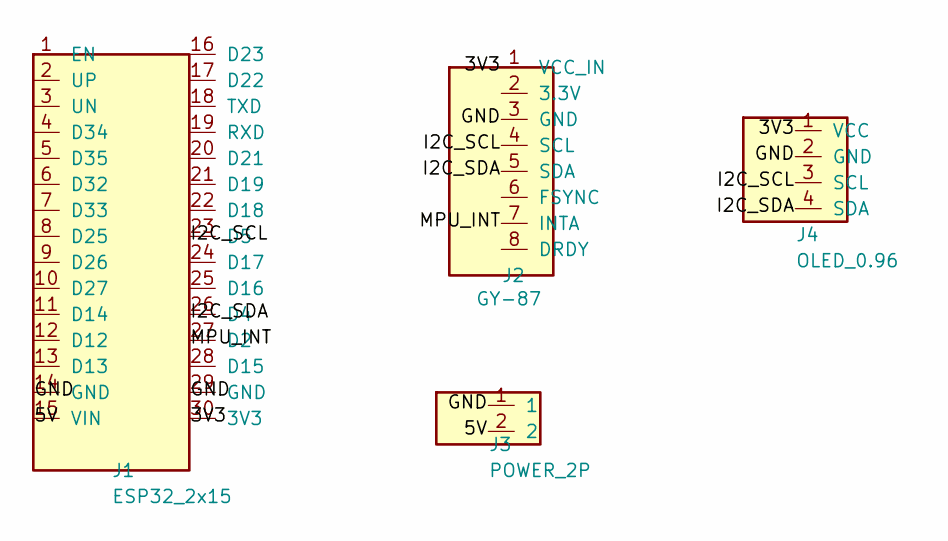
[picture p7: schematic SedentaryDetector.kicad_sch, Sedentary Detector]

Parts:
J1: ESP32_2x15
J2: GY-87
J3: POWER_2P
J4: OLED_0.96

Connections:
3V3: J1.30 (3V3), J2.1 (VCC_IN), J4.1 (VCC)
5V: J1.15 (VIN), J3.2
GND: J1.14 (GND), J1.29 (GND), J2.3 (GND), J3.1, J4.2 (GND)
I2C_SCL: J1.23 (D5), J2.4 (SCL), J4.3 (SCL)
I2C_SDA: J1.26 (D4), J2.5 (SDA), J4.4 (SDA)
MPU_INT: J1.27 (D2), J2.7 (INTA)

Board: 2 copper layers, 8 parts (0 on the bottom side), 6 nets, no tracks yet.

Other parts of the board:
MH1, MH2, MH3, MH4: (no value)

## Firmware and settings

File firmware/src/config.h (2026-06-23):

#pragma once

// GY-87 联调 / 载板 J2：D4=SDA, D5=SCL, D2=INTA（见 hardware/HARDWARE.md）
constexpr int PIN_I2C_SDA = 4;   // D4
constexpr int PIN_I2C_SCL = 5;   // D5
constexpr int PIN_MPU_INT = 2;   // D2，与 DevKit 板载 LED 共用
constexpr int PIN_LED = 2;

constexpr uint8_t MPU_ADDR = 0x68;

constexpr uint8_t OLED_ADDR = 0x3C;
constexpr int OLED_WIDTH = 128;
constexpr int OLED_HEIGHT = 64;

constexpr unsigned long SAMPLE_INTERVAL_MS = 2000;
constexpr int DEBOUNCE_COUNT = 3;
constexpr int SEDENTARY_MINUTES = 45;
constexpr float ANGLE_OCCUPIED_DEG = 1.0f;
constexpr float ANGLE_VACANT_DEG = 0.5f;

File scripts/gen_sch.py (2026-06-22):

"""从 HARDWARE.md 网络表生成载板原理图骨架（ESP32-WROOM-32 2×15 + GY-87 1×8）。"""

import uuid
from pathlib import Path

ROOT = Path(__file__).resolve().parents[1]
# 默认写入 .gen 文件，避免覆盖 KiCad GUI 中手工维护的原理图
DST = ROOT / "hardware/kicad/SedentaryDetector.gen.kicad_sch"

ESP_NUM_PINS = 30

# DevKitC 排针编号 → 功能名（见 hardware/HARDWARE.md）
ESP_PIN_NAMES = {
    1: "3V3",
    2: "EN",
    3: "GPIO36",
    4: "GPIO39",
    5: "GPIO34",
    6: "GPIO35",
    7: "GPIO32",
    8: "GPIO33",
    9: "GPIO25",
    10: "GPIO26",
    11: "GPIO27",
    12: "GPIO14",
    13: "GPIO12",
    14: "GND",
    15: "VIN",
    16: "GPIO23",
    17: "GPIO22",
    18: "GPIO21",
    19: "GND",
    20: "GPIO19",
    21: "GPIO18",
    22: "GPIO5/SCL",
    23: "GPIO17",
    24: "GPIO16",
    25: "GPIO4/SDA",
    26: "GPIO2/INT",
    27: "GPIO15",
    28: "GND",
    29: "3V3",
    30: "30",
}

# 载板已用网络对应的 ESP 排针编号
PIN_3V3 = 1
PIN_GND_LEFT = 14
PIN_VIN = 15
PIN_GND_MID = 19
PIN_SCL = 22
PIN_SDA = 25
PIN_INT = 26
PIN_GND_RIGHT = 28

USED_ESP_PINS = {
    PIN_3V3,
    PIN_GND_LEFT,
    PIN_VIN,
    PIN_GND_MID,
    PIN_SCL,
    PIN_SDA,
    PIN_INT,
    PIN_GND_RIGHT,
}


def gen_uuid():
    return str(uuid.uuid4())


uuids = {k: gen_uuid() for k in [
    "file", "esp_sym", "mpu_sym",
    "pwr_gnd1", "pwr_gnd2", "pwr_3v3",
    "pwr_gnd1_pin", "pwr_gnd2_pin", "pwr_3v3_pin",
]}
for i in range(1, ESP_NUM_PINS + 1):
    uuids[f"esp_pin{i}"] = gen_uuid()
for i in range(1, 9):
    uuids[f"mpu_pin{i}"] = gen_uuid()
for i in range(1, 12):
    uuids[f"wire{i}"] = gen_uuid()
for i in range(1, 5):
    uuids[f"junc{i}"] = gen_uuid()
for name in ["label_gnd", "label_3v3", "label_5v", "label_sda", "label_scl", "label_int"]:
    uuids[name] = gen_uuid()
nc_idx = 0
for pin in range(1, ESP_NUM_PINS + 1):
    if pin not in USED_ESP_PINS:
        nc_idx += 1
        uuids[f"nc{nc_idx}"] = gen_uuid()
for pin in (1, 3, 7):
    uuids[f"nc_mpu{pin}"] = gen_uuid()


def conn_02x15_pin_lines(side: str, start_num: int, count: int) -> list[str]:
    lines = []
    x = -7.62 if side == "left" else 7.62
    for i in range(count):
        num = start_num + i
        y = 20.32 - i * 2.54
        name = ESP_PIN_NAMES.get(num, str(num))
        lines.append(
            f"""				(pin passive line (at {x} {y} 0) (length 2.54)
          (name "{name}" (effects (font (size 1.27 1.27))))
          (number "{num}" (effects (font (size 1.27 1.27))))
        )"""
        )
    return lines


esp_symbol_pins = conn_02x15_pin_lines("left", 1, 15) + conn_02x15_pin_lines("right", 16, 15)

esp_symbol = f"""(symbol "Conn_02x15" (pin_names (offset 1.016)) (in_bom yes) (on_board yes)
			(property "Reference" "J1" (at 0 20.32 0)
        (effects (font (size 1.27 1.27)) (justify left))
      )
			(property "Value" "ESP32_2x15" (at 0 22.86 0)
        (effects (font (size 1.27 1.27)) (justify left))
      )
			(property "Footprint" "" (at 0 -20.32 0)
        (effects (font (size 1.27 1.27)) hide)
      )
			(property "Datasheet" "" (at 0 0 0)
        (effects (font (size 1.27 1.27)) hide)
      )
			(symbol "Conn_02x15_0_1"
        (rectangle (start -7.62 20.32) (end 7.62 -20.32)
          (stroke (width 0.254) (type default))
          (fill (type background))
        )
      )
			(symbol "Conn_02x15_1_1"
{chr(10).join(esp_symbol_pins)}
      )
    )"""

mpu_pins = []
mpu_pin_names = {
    1: "DRDY",
    2: "INTA",
    3: "FSYNC",
    4: "SDA",
    5: "SCL",
    6: "GND",
    7: "3.3V",
    8: "VCC_IN",
}
for i in range(1, 9):
    y = 8.89 - (i - 1) * 2.54
    mpu_pins.append(
        f"""				(pin passive line (at 0 {y} 0) (length 2.54)
          (name "{mpu_pin_names[i]}" (effects (font (size 1.27 1.27))))
          (number "{i}" (effects (font (size 1.27 1.27))))
        )"""
    )

mpu_symbol = f"""(symbol "CarrierBoard:GY87_1x8" (pin_numbers hide) (pin_names (offset 1.016)) (in_bom yes) (on_board yes)
			(property "Reference" "J2" (at 0 -11.43 0)
        (effects (font (size 1.27 1.27)) (justify top))
      )
			(property "Value" "GY-87_1x8" (at 0 -13.97 0)
        (effects (font (size 1.27 1.27)) hide)
      )
			(property "Footprint" "Connector_PinSocket_2.54mm:PinSocket_1x08_P2.54mm_Vertical" (at 0 12.7 0)
        (effects (font (size 1.27 1.27)) hide)
      )
			(property "Datasheet" "" (at 0 0 0)
        (effects (font (size 1.27 1.27)) hide)
      )
			(symbol "GY87_1x8_0_1"
        (rectangle (start -5.08 -11.43) (end 5.08 11.43)
          (stroke (width 0.254) (type default))
          (fill (type background))
        )
      )
			(symbol "GY87_1x8_1_1"
{chr(10).join(mpu_pins)}
      )
    )"""

lib_symbols = f"""  (lib_symbols
{esp_symbol}
{mpu_symbol}
		(symbol "power:GND" (power) (pin_names (offset 0)) (in_bom yes) (on_board yes)
			(property "Reference" "#PWR" (at 0 -6.35 0)
        (effects (font (size 1.27 1.27)) hide)
      )
			(property "Value" "GND" (at 0 -3.81 0)
        (effects (font (size 1.27 1.27)))
      )
			(property "Footprint" "" (at 0 0 0)
        (effects (font (size 1.27 1.27)) hide)
      )
			(property "Datasheet" "" (at 0 0 0)
        (effects (font (size 1.27 1.27)) hide)
      )
			(symbol "GND_0_1"
        (polyline
          (pts (xy 0 0) (xy 0 -1.27) (xy 1.27 -1.27) (xy 0 -2.54) (xy -1.27 -1.27) (xy 0 -1.27))
          (stroke (width 0) (type default))
          (fill (type none))
        )
      )
			(symbol "GND_1_1"
				(pin power_in line (at 0 0 270) (length 0) hide
          (name "GND" (effects (font (size 1.27 1.27))))
          (number "1" (effects (font (size 1.27 1.27))))
        )
      )
    )
		(symbol "power:VCC" (power) (pin_names (offset 0)) (in_bom yes) (on_board yes)
			(property "Reference" "#PWR" (at 0 -3.81 0)
        (effects (font (size 1.27 1.27)) hide)
      )
			(property "Value" "+3V3" (at 0 3.81 0)
        (effects (font (size 1.27 1.27)))
      )
			(property "Footprint" "" (at 0 0 0)
        (effects (font (size 1.27 1.27)) hide)
      )
			(property "Datasheet" "" (at 0 0 0)
        (effects (font (size 1.27 1.27)) hide)
      )
			(symbol "+3V3_0_1"
        (polyline
          (pts (xy -1.27 1.27) (xy 0 2.54) (xy 1.27 1.27))
          (stroke (width 0) (type default))
          (fill (type none))
        )
        (polyline
          (pts (xy 0 0) (xy 0 2.54))
          (stroke (width 0) (type default))
          (fill (type none))
        )
      )
			(symbol "+3V3_1_1"
				(pin power_in line (at 0 0 90) (length 0) hide
          (name "+3V3" (effects (font (size 1.27 1.27))))
          (number "1" (effects (font (size 1.27 1.27))))
        )
      )
    )
  )"""

esp_at_x, esp_at_y = 50, 100
mpu_at_x, mpu_at_y = 170, 80


def esp_pin_abs(pin_num: int) -> tuple[float, float]:
    if pin_num <= 15:
        px = esp_at_x - 7.62
        py = esp_at_y + (20.32 - (pin_num - 1) * 2.54)
    else:
        px = esp_at_x + 7.62
        py = esp_at_y + (20.32 - (pin_num - 16) * 2.54)
    return (px, py)
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

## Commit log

2026-06-19 docs: 添加当前进度表
2026-06-20 feat: PC端单元测试 (8个用例全通过)
    - detector: 角度检测+去抖+久坐计时算法
    - mpu6050_sim: MPU6050数据模拟器
    - test: 8个测试用例覆盖坐下/站起/久坐/噪声/完整场景
    - 结果: 8 run, 0 failed
2026-06-20 fix(hardware): add KiCad library tables to resolve symbol/footprint loading
    - sym-lib-table: Connector_Generic, Device, power libraries
    - fp-lib-table: Connector_PinHeader_2.54mm footprint library
    - Uses absolute paths to /usr/share/kicad/ (KiCad 7.0.11 apt install)
    Fixes: 'Can't find library file' error in KiCad GUI
2026-06-20 feat(hardware): regenerate PCB with KiCad 10 pcbnew API
    Use KiCad 10 system pcbnew API (via kicad-python wrapper):
    - Board: 50x35mm, 2-layer, 1.6mm (KiCad 10 format)
    - J1: ESP32-C3 2x9 (PinSocket, THT pads)
    - J2: MPU6050 1x8 (PinSocket, THT pads)
    - GND copper pour on B.Cu layer
    - Net declarations for all ESP32 + MPU6050 pins
    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
    [SedentaryDetector.kicad_pcb]
2026-06-20 feat(hardware): ESP32-WROOM-32 2x15 + MPU6050 1x8 PCB layout
    PCB (KiCad 10 pcbnew API):
    - Board: 80x50mm, centered layout
    - J1: ESP32-WROOM-32 2x15 header @ (-30, -17.8)mm
    - J2: MPU6050 GY-521 1x8 header @ (30, -7.6)mm
    - GND copper pour on B.Cu
    - M3 mounting holes at 4 corners
    - Net assignments: GND, 3V3, I2C_SDA, I2C_SCL, MPU_INT, VIN_SW
    Dimensions: 24.5mm row spacing, 2.54mm pin pitch
    Schematics: in KiCad GUI (hand-writing S-expr format is error-prone)
    [SedentaryDetector.kicad_pcb, SedentaryDetector.kicad_sch]
2026-06-20 feat(hardware): 80x50mm PCB with silk annotations
    Board: 80x50mm, no traces (placement only)
    J1: 2x15 @ x=-22..1.5mm (23.5mm row spacing)
    J2: 1x8 @ x=22mm
    Silk annotations: 23.5mm, 2.54mm pitch, board size
    M3 mounting holes at 4 corners
    [SedentaryDetector.kicad_pcb]
2026-06-20 fix(hardware): shift board to positive coords for correct PDF export
    Board shifted by (+45,+28)mm - now all elements in positive quadrant
    PDF exports correctly with --mode-single --scale 0
    [SedentaryDetector.kicad_pcb]
2026-06-20 docs(hardware): update HARDWARE.md for ESP32-WROOM-32
    - Module: ESP32-C3 Mini → ESP32-WROOM-32
    - Dimensions: 25.4×18mm → 51.85×23.5mm
    - Pins: 2×9 → 2×15, row spacing 23.5mm
    - MPU6050: 21×16mm → 15.6×20.2mm, ~15g
    - PCB: 50×35mm → 80×50mm
    - Mounting holes: 4× φ3mm at corners
    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
2026-06-20 feat(hardware): clean PCB layout with 1cm grid
    - Removed misplaced title/footprint texts
    - Added 1cm coordinate grid along edges (0-80mm X, 0-50mm Y)
    - J1 (2x15) and J2 (1x8) properly placed
    - No traces (to be added in KiCad GUI)
    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
    [SedentaryDetector.kicad_pcb]
2026-06-20 fix(hardware): clean PCB - only pin labels, J2 moved right
    - J1 (2x15): left column EN→GPIO2, right column GND→VCC
    - J2 (1x8): VCC, GND, SCL, SDA, XDA, XCL, AD0, INT
    - All other silk removed (titles, outlines, dimensions)
    - J2 pads moved to right side to avoid overlap
    [SedentaryDetector.kicad_pcb]
2026-06-20 fix(hardware): clean PCB with only pin labels
    - J1 (ESP32 2x15): Left: EN,GPIO15→GPIO2; Right: GND,VIN,GPIO23→GND
    - J2 (MPU6050 1x8): VCC,GND,SCL,SDA,XDA,XCL,AD0,INT
    - No titles, no outlines, no dimension lines - only pin labels
    - B.Cu GND copper pour
2026-06-20 fix(hardware): correct 30-pin ESP32-WROOM-32 layout
    - Left column P1-P15: VIN,GND,GPIO13-36,EN (matching image)
    - Right column P16-P30: GPIO23-13,GND,VCC,NC
    - J2 P1-P8: VCC,GND,SCL,SDA,XDA,XCL,AD0,INT
    - 15 pins per column, correct pin numbering
    [SedentaryDetector.kicad_pcb]
2026-06-20 Simplify silk: left P1-15, right P1+P14 only, J2 P1-8
    [SedentaryDetector.kicad_pcb]
2026-06-20 PCB silk: both columns fully labeled (left P1-15, right P1-14, J2 P1-8)
    [SedentaryDetector.kicad_pcb]
2026-06-20 feat(hardware): commit all hardware files for 100x80mm board
    [SedentaryDetector.kicad_pcb]
2026-06-20 V0.1: Phase 1 complete — 100x80mm PCB, 3 female headers, clean silk
2026-06-20 chore: update PCB and scripts
    [SedentaryDetector.kicad_pcb]
2026-06-20 docs(hardware): switch to Type-C battery, add switch pinout, update BOM
2026-06-20 fix(hardware): add missing Edge.Cuts board outline (100x80mm)
    [SedentaryDetector.kicad_pcb]
2026-06-20 docs: add control circuit wiring table (ESP32 ↔ MPU6050)
    [SedentaryDetector.kicad_pcb]
2026-06-20 V0.2: user hand-routed PCB, 31 tracks
2026-06-20 fix(schematic): create matching schematic for J1(2x15) J2(1x8)
    [SedentaryDetector.kicad_sch]
2026-06-20 fix(hardware): assign nets, GND pour - user to route
    [SedentaryDetector.kicad_pcb, SedentaryDetector.kicad_sch]
2026-06-20 V0.3: PCB layout ready for routing
    [SedentaryDetector.kicad_pcb]
2026-06-20 feat(hardware): add tight Edge.Cuts border 30x62mm
    [SedentaryDetector.kicad_pcb]
2026-06-20 feat(hardware): add M4 mounting holes at 4 corners
    [SedentaryDetector.kicad_pcb]
2026-06-20 fix: PCB restored from V0.4
2026-06-22 docs: 统一主控为 ESP32-WROOM-32，澄清目录名遗留
    实际硬件与载板为 WROOM-32 DevKitC，非 ESP32-C3；补充固件联调指南入口。
2026-06-22 fix(scripts): gen_sch 改为 ESP32-WROOM-32 2×15 接线
    替换 ESP32-C3 2×9 符号，按 HARDWARE.md 映射 GPIO4/5/2 与 3V3/GND/VIN；默认输出 .gen.kicad_sch 避免覆盖手工原理图。
    [gen_sch.py]
2026-06-22 docs/hardware: 正式选型 GY-87 并修正 J2 引脚顺序
    联调验证 MPU6050 后统一文档与 KiCad 原理图 v0.5.1（背面照片导致 Pin1–8 反转）；补充固件源码与 GY-87 实物图。
    [SedentaryDetector.kicad_pcb, SedentaryDetector.kicad_sch]
2026-06-23 hardware: 载板简化为 MCU/IMU/OLED/电源 v0.6
    移除载板滑动开关与 CAL/OK 按键；更新 KiCad 原理图/PCB、文档与固件配套改动。
    [SedentaryDetector.kicad_pcb, SedentaryDetector.kicad_sch]
